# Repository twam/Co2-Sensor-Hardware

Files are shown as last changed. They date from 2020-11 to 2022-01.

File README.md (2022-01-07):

Co2-Sensor-Hardware
===

This repository is the hoftware part of the software project https://github.com/twam/Co2-Sensor-Software.

### Images

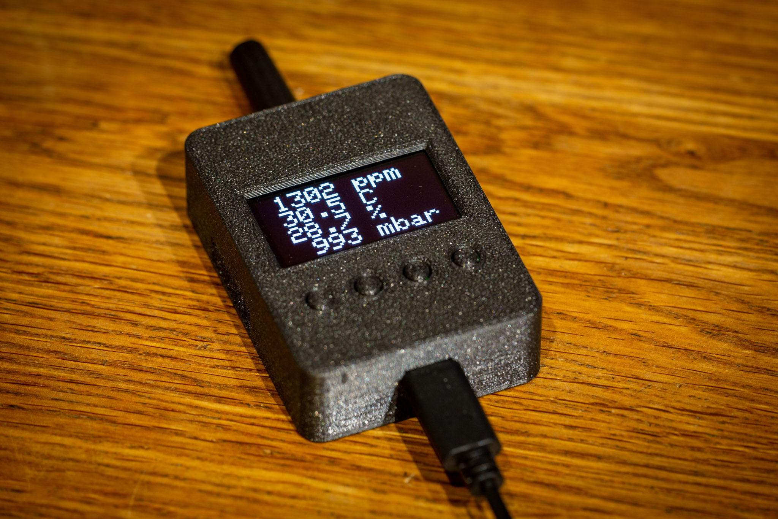
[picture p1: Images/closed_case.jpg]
Closed case

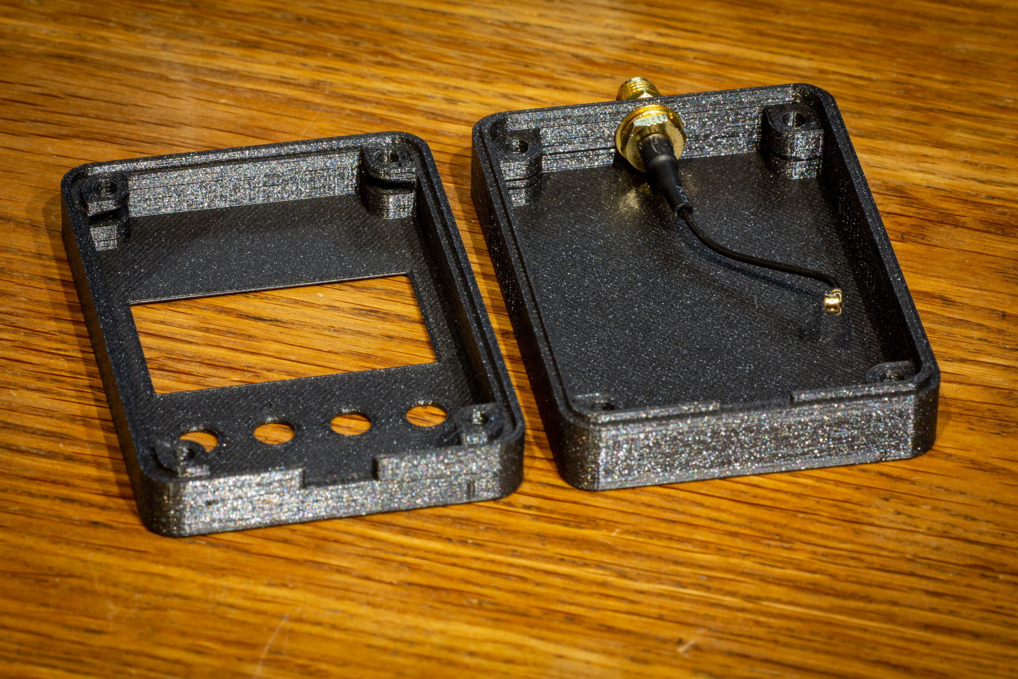
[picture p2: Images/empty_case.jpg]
Empty case

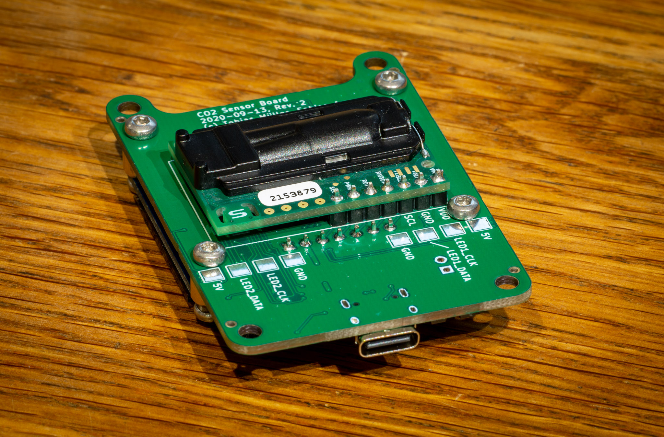
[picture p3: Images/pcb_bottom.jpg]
PCB bottom

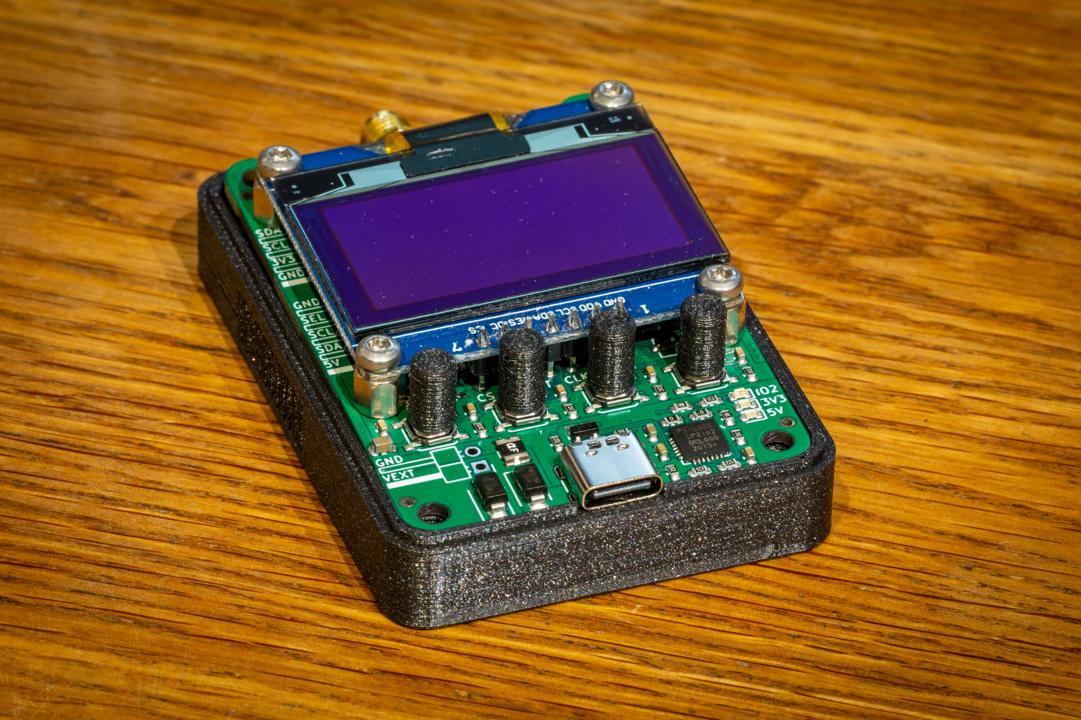
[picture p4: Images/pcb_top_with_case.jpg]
PCB top


### JLCPCB

PCBs can be ordered almost fully-assembled from [JLCPCB](https://jlcpcb.com/DDE). Required files are
[Co2-Sensor_bom_jlc.csv](Gerber/Co2-Sensor_bom_jlc.csv), [Co2-Sensor_cpl_jlc.csv](Gerber/Co2-Sensor_cpl_jlc.csv) and
[Co2-Sensor.zip](Co2-Sensor.zip). Components missing are
* Co2 Sensor (J2)
* USB connector (J5) – can be also populated in the mean time, but is not included in production files, yet.

## License

[][cc-by-sa]

This work is licensed under a [Creative Commons Attribution-NonCommercial-ShareAlike 4.0 International License][cc-by-sa].

[][cc-by-sa]

[cc-by-sa]: http://creativecommons.org/licenses/by-nc-sa/4.0/
[cc-by-sa-image]: https://licensebuttons.net/l/by-nc-sa/4.0/88x31.png
[cc-by-sa-shield]: https://img.shields.io/badge/License-CC%20BY--NC--SA%204.0-lightgrey.svg

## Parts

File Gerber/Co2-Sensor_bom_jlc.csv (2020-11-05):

Comment | Designator | Footprint | LCSC Part #
100n/50V | C2,C8,C9,C10,C11,C12,C13 | C_0603_1608Metric | C14663
1u/50V | C3 | C_0603_1608Metric | C15849
22u/25V | C4,C1,C14,C15 | C_0805_2012Metric | C45783
10u/10V | C5,C6 | C_0603_1608Metric | C19702
2u2/16V | C7 | C_0603_1608Metric | C23630
Green | D1,D4 | LED_0603_1608Metric | C72043
SS14 | D2,D6 | D_SMA | C2480
SP0503BAHT | D3 | SOT-143 | C7074
Yellow | D5 | LED_0603_1608Metric | C72038
SMD1210-050 | F1 | Fuse_1210_3225Metric | C70094
S8050 | Q1,Q2 | SOT-23 | C2146
2N7002 | Q3,Q4 | SOT-23 | C8545
0R | R5,R6,R33,R32,R30 | R_0603_1608Metric | C21189
10k | R7,R8,R3,R1,R17,R23,R27,R25 | R_0603_1608Metric | C25804
5k1 | R12,R11 | R_0603_1608Metric | C23186
24k | R13 | R_0603_1608Metric | C23352
47k | R14 | R_0603_1608Metric | C25819
4k7 | R15,R16 | R_0603_1608Metric | C23162
15k | R18 | R_0603_1608Metric | C22809
1k5 | R19 | R_0603_1608Metric | C22843
12k | R20 | R_0603_1608Metric | C22790
USER1 | SW1 | SW_SPST_XKB_TS-1187A-X-X-X | C318886
USER2 | SW2 | SW_SPST_XKB_TS-1187A-X-X-X | C318886
USER3 | SW3 | SW_SPST_XKB_TS-1187A-X-X-X | C318886
PROGRAM | SW4 | SW_SPST_XKB_TS-1187A-X-X-X | C318886
AMS1117-3.3 | U2 | SOT-223-3_TabPin2 | C6186
CP2102 | U3 | QFN-28-1EP_5x5mm_P0.5mm_EP3.35x3.35mm | C6568
74LVC1G02 | U5 | SOT-23-5 | C16360

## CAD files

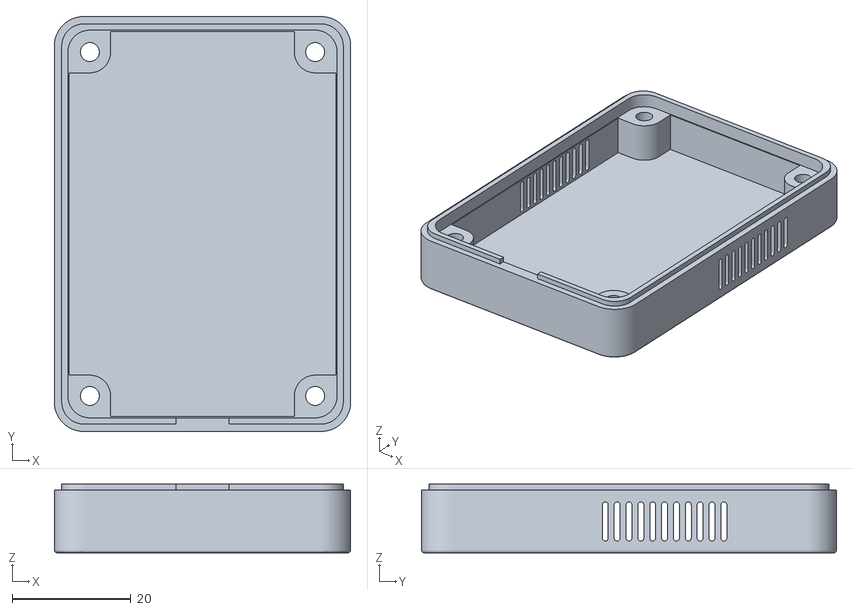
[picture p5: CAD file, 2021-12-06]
Case/Bottom_SideVentilation.stl
50.0 x 70.0 x 11.6

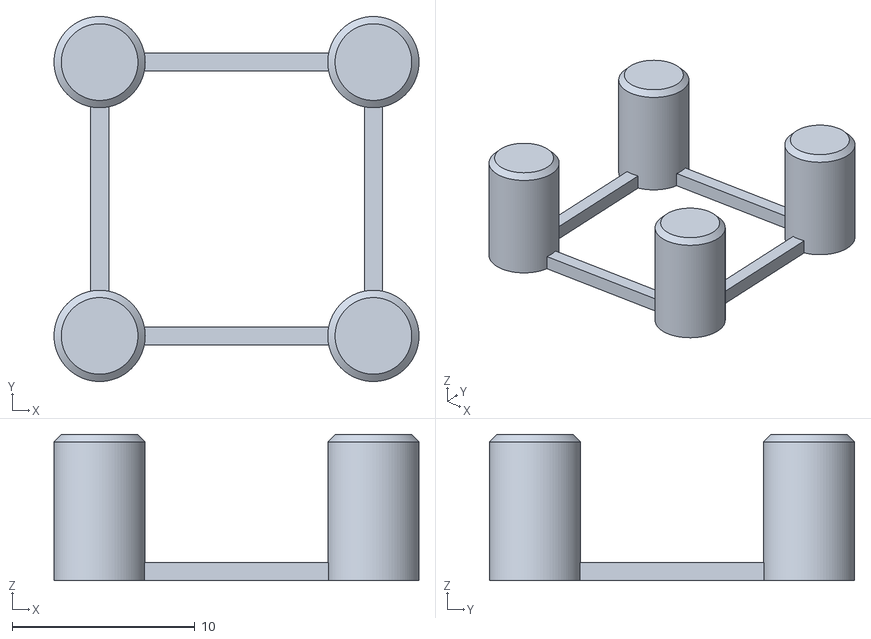
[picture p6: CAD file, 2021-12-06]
Case/Cap_4x.stl
20.0 x 20.0 x 8.00

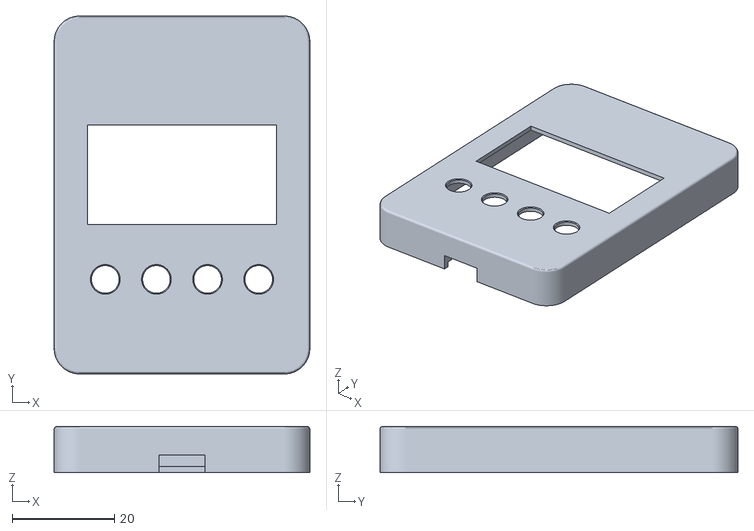
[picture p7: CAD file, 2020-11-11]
Case/Top.stl
50.0 x 70.0 x 9.00

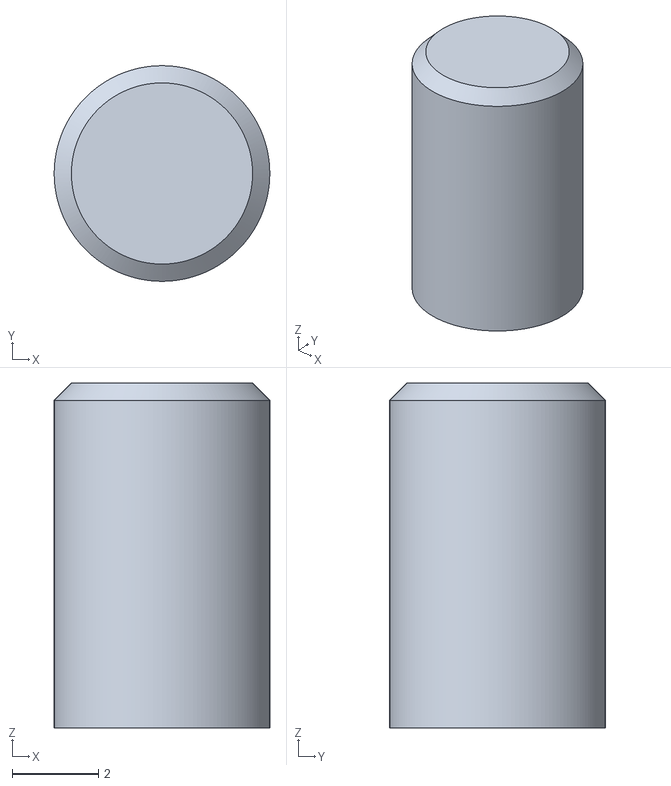
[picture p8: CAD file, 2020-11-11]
Case/Cap.stl
5.00 x 5.00 x 8.00

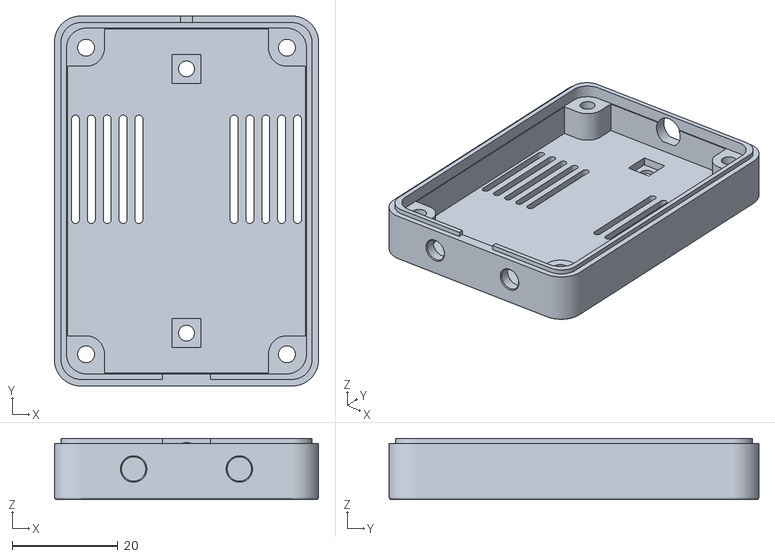
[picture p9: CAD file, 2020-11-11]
Case/Bottom_BottomVentilation_AntennaConnector_LEDCableOutlets.stl
50.0 x 70.0 x 11.6

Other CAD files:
Case/Bottom_SideVentTop.stl
Case/Bottom_SideVentTop_Ant.stl
Case/Bottom_SideVentilation_Ant.stl

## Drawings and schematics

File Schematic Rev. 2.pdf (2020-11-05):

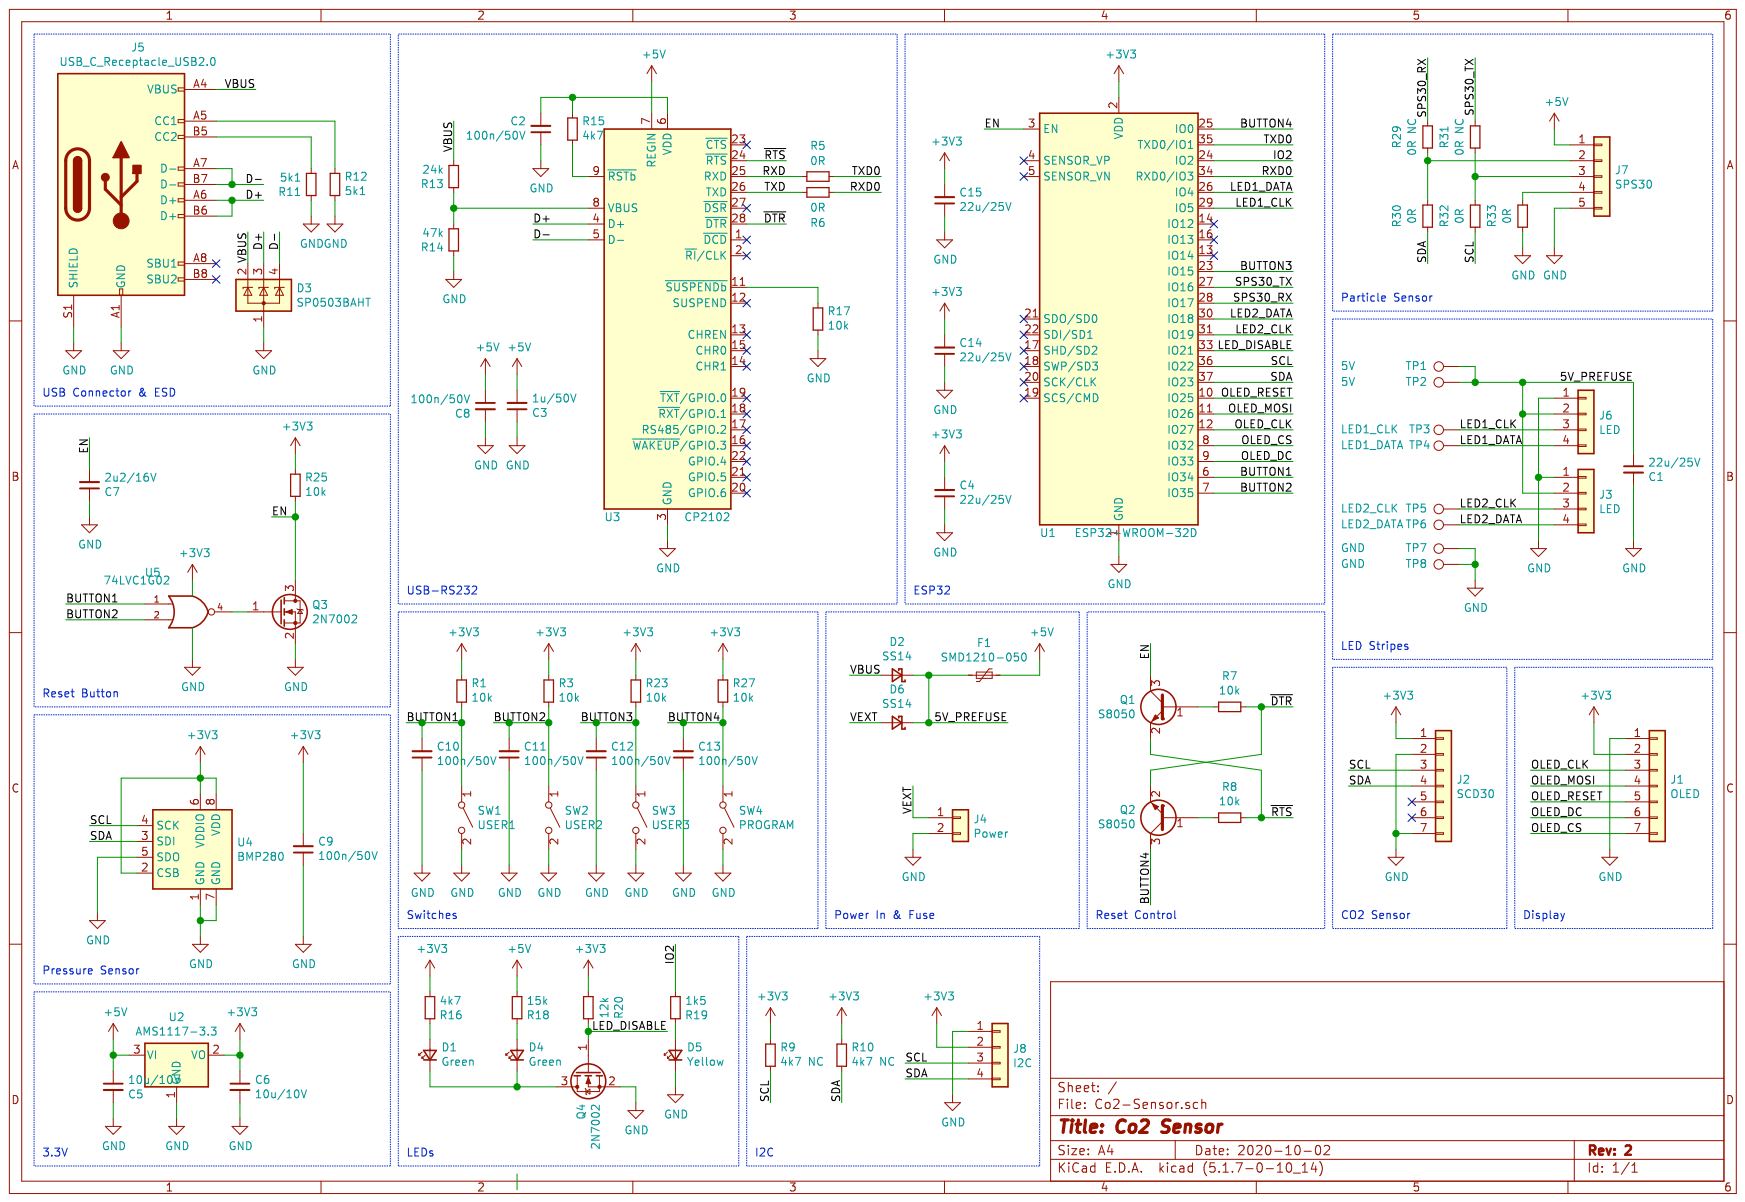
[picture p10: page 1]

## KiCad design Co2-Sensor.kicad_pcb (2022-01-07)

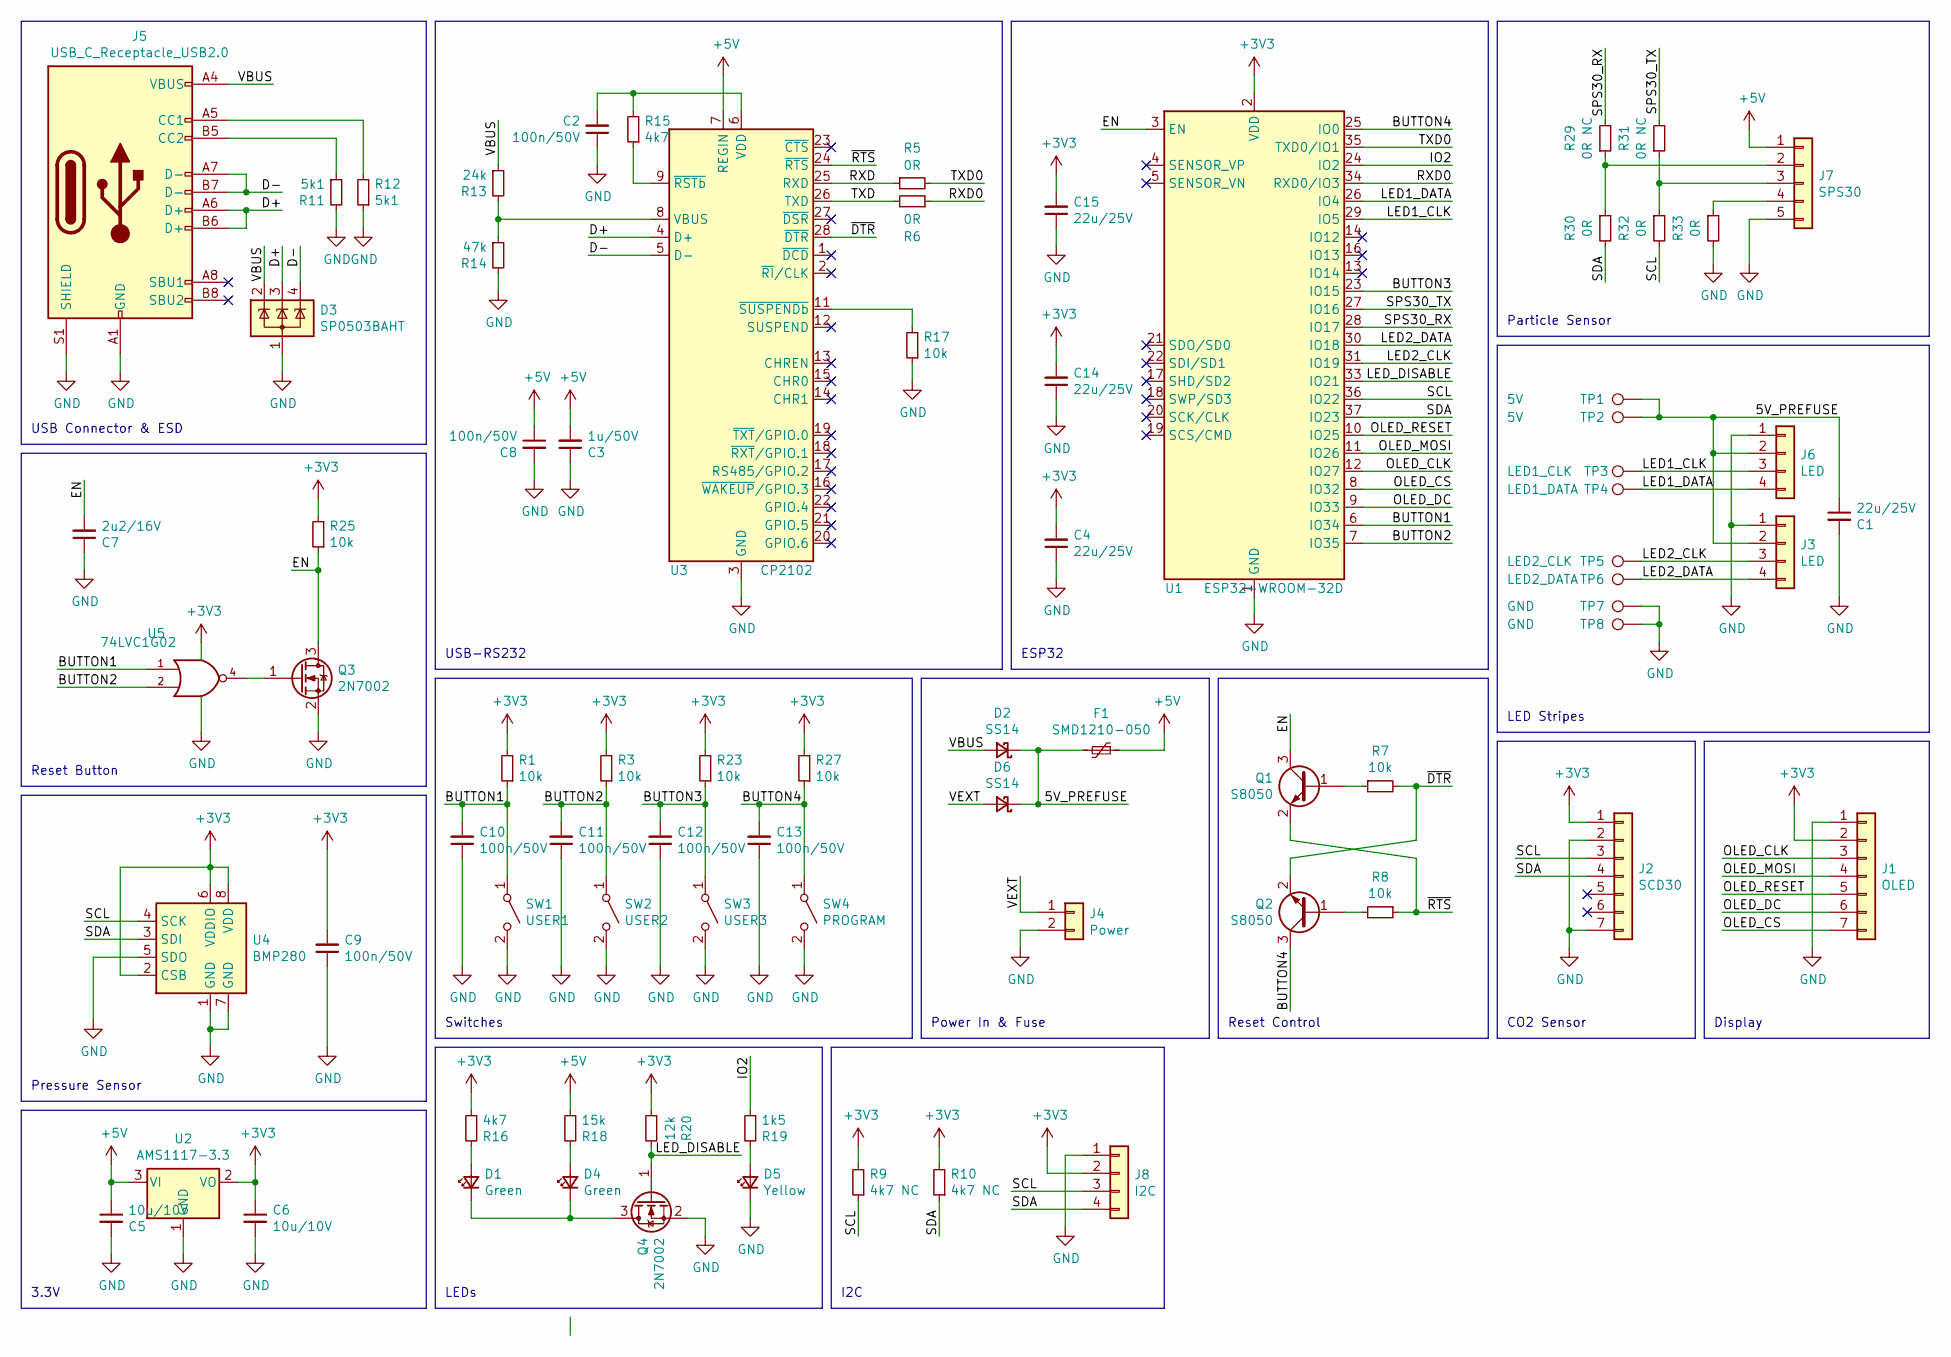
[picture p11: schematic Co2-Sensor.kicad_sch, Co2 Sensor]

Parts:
C1, C4, C14, C15: 22u/25V; C_0805_2012Metric; LCSC C45783
C2, C8, C9, C10, C11, C12, C13: 100n/50V; C_0603_1608Metric; LCSC C14663
C3: 1u/50V; C_0603_1608Metric; LCSC C15849
C5, C6: 10u/10V; C_0603_1608Metric; LCSC C19702
C7: 2u2/16V; C_0603_1608Metric; LCSC C23630
D1, D4: Green; LED_0603_1608Metric; LCSC C72043
D2, D6: SS14; D_SMA; LCSC C2480
D3: SP0503BAHT; SOT-143; LCSC C7074
D5: Yellow; LED_0603_1608Metric; LCSC C72038
F1: SMD1210-050; Fuse_1210_3225Metric; LCSC C70094
J1: OLED; TZT_154
J2: SCD30; Sensiron_SCD30
J3, J6: LED; PinHeader_1x04_P2.54mm_Horizontal
J4: Power; PinHeader_1x02_P2.54mm_Horizontal
J5: USB_C_Receptacle_USB2.0; USB_C_Receptacle_XKB_U262-16XN-4BVC11
J7: SPS30; PinHeader_1x05_P2.54mm_Horizontal
J8: I2C; PinHeader_1x04_P2.54mm_Horizontal
Q1, Q2: S8050; SOT-23; LCSC C2146
Q3, Q4: 2N7002; SOT-23; LCSC C8545
R1, R3, R7, R8, R17, R23, R25, R27: 10k; R_0603_1608Metric; LCSC C25804
R5, R6, R30, R32, R33: 0R; R_0603_1608Metric; LCSC C21189
R9, R10: 4k7 NC; R_0603_1608Metric
R11, R12: 5k1; R_0603_1608Metric; LCSC C23186
R13: 24k; R_0603_1608Metric; LCSC C23352
R14: 47k; R_0603_1608Metric; LCSC C25819
R15, R16: 4k7; R_0603_1608Metric; LCSC C23162
R18: 15k; R_0603_1608Metric; LCSC C22809
R19: 1k5; R_0603_1608Metric; LCSC C22843
R20: 12k; R_0603_1608Metric; LCSC C22790
R29, R31: 0R NC; R_0603_1608Metric
SW1: USER1; SW_SPST_XKB_TS-1187A-X-X-X; LCSC C318886
SW2: USER2; SW_SPST_XKB_TS-1187A-X-X-X; LCSC C318886
SW3: USER3; SW_SPST_XKB_TS-1187A-X-X-X; LCSC C318886
SW4: PROGRAM; SW_SPST_XKB_TS-1187A-X-X-X; LCSC C318886
TP1, TP2: 5V; TestPoint_Pad_2.5x2.5mm
TP3: LED1_CLK; TestPoint_Pad_2.5x2.5mm
TP4: LED1_DATA; TestPoint_Pad_2.5x2.5mm
TP5: LED2_CLK; TestPoint_Pad_2.5x2.5mm
TP6: LED2_DATA; TestPoint_Pad_2.5x2.5mm
TP7, TP8: GND; TestPoint_Pad_2.5x2.5mm
U1: ESP32-WROOM-32D; ESP32-WROOM-32
U2: AMS1117-3.3; SOT-223-3_TabPin2; LCSC C6186
U3: CP2102; QFN-28-1EP_5x5mm_P0.5mm_EP3.35x3.35mm; LCSC C6568
U4: BMP280; Bosch_LGA-8_2x2.5mm_P0.65mm_ClockwisePinNumbering; LCSC C83291
U5: 74LVC1G02; SOT-23-5; LCSC C16360

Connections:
+3V3: C4.2, C6.1, C9.2, C14.2, C15.2, J1.2, J2.1, J8.2, R1.2, R3.2, R9.2, R10.2, R16.1, R20.1, R23.2, R25.2, R27.2, U1.2 (VDD), U2.2 (VO), U4.2 (CSB), U4.6 (VDDIO), U4.8 (VDD), U5.5 (VCC)
+5V: C3.2, C5.1, C8.1, F1.1, J7.1, R18.1, U2.3 (VI), U3.7 (REGIN)
/5V_PREFUSE: C1.1, D2.1 (K), D6.1 (K), F1.2, J3.2, J6.2, TP1.1, TP2.1
/BUTTON1: C10.2, R1.1, SW1.1 (A), U1.6 (IO34), U5.1
/BUTTON2: C11.2, R3.1, SW2.1 (A), U1.7 (IO35), U5.2
/BUTTON3: C12.2, R23.1, SW3.1 (A), U1.23 (IO15)
/BUTTON4: C13.2, Q2.3 (C), R27.1, SW4.1 (A), U1.25 (IO0)
/D+: D3.3 (K), J5.A6 (D+), J5.B6 (D+), U3.4 (D+)
/D-: D3.4 (K), J5.A7 (D-), J5.B7 (D-), U3.5 (D-)
/EN: C7.2, Q1.3 (C), Q3.3 (D), R25.1, U1.3 (EN)
/IO2: R19.1, U1.24 (IO2)
/LED1_CLK: J6.3, TP3.1, U1.29 (IO5)
/LED1_DATA: J6.4, TP4.1, U1.26 (IO4)
/LED2_CLK: J3.3, TP5.1, U1.31 (IO19)
/LED2_DATA: J3.4, TP6.1, U1.30 (IO18)
/LED_DISABLE: Q4.1 (G), R20.2, U1.33 (IO21)
/OLED_CLK: J1.3, U1.12 (IO27)
/OLED_CS: J1.7, U1.8 (IO32)
/OLED_DC: J1.6, U1.9 (IO33)
/OLED_MOSI: J1.4, U1.11 (IO26)
/OLED_RESET: J1.5, U1.10 (IO25)
/RXD: R5.1, U3.25 (RXD)
/RXD0: R6.1, U1.34 (RXD0/IO3)
/SCL: J2.3, J8.3, R9.1, R32.2, U1.36 (IO22), U4.4 (SCK)
/SDA: J2.4, J8.4, R10.1, R30.2, U1.37 (IO23), U4.3 (SDI)
/SPS30_RX: R29.2, U1.28 (IO17)
/SPS30_TX: R31.2, U1.27 (IO16)
/TXD: R6.2, U3.26 (TXD)
/TXD0: R5.2, U1.35 (TXD0/IO1)
/VBUS: D2.2 (A), D3.2 (K), J5.A4 (VBUS), J5.A9 (VBUS), J5.B4 (VBUS), J5.B9 (VBUS), R13.1
/VEXT: D6.2 (A), J4.1
/~DTR: Q2.2 (E), R7.2, U3.28 (~DTR)
/~RTS: Q1.2 (E), R8.1, U3.24 (~RTS)
GND: C1.2, C2.1, C3.1, C4.1, C5.2, C6.2, C7.1, C8.2, C9.1, C10.1, C11.1, C12.1, C13.1, C14.1, C15.1, D3.1 (A), D5.1 (K), J1.1, J2.2, J2.7, J3.1, J4.2, J5.A1 (GND), J5.A12 (GND), J5.B1 (GND), J5.B12 (GND), J5.S1 (SHIELD), J6.1, J7.5, J8.1, Q3.2 (S), Q4.2 (S), R11.2, R12.1, R14.2, R17.1, R33.2, SW1.2 (B), SW2.2 (B), SW3.2 (B), SW4.2 (B), TP7.1, TP8.1, U1.1 (GND), U1.15 (GND), U1.38 (GND), U1.39 (GND), U2.1 (GND), U3.3 (GND), U3.29 (GND), U4.1 (GND), U4.5 (SDO), U4.7 (GND), U5.3 (GND)
unnamed: C2.2, R15.2, U3.6 (VDD)
unnamed: D1.1 (K), D4.1 (K), Q4.3 (D)
unnamed: D1.2 (A), R16.2
unnamed: D4.2 (A), R18.2
unnamed: D5.2 (A), R19.2
unnamed: J5.A5 (CC1), R12.2
unnamed: J5.B5 (CC2), R11.1
unnamed: J7.2, R29.1, R30.1
unnamed: J7.3, R31.1, R32.1
unnamed: J7.4, R33.1
unnamed: Q1.1 (B), R7.1
unnamed: Q2.1 (B), R8.2
unnamed: Q3.1 (G), U5.4
unnamed: R13.2, R14.1, U3.8 (VBUS)
unnamed: R15.1, U3.9 (~RSTb)
unnamed: R17.2, U3.11 (~SUSPENDb)

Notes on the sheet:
LED Stripes
I2C
Reset Control
CO2 Sensor
Switches
ESP32
Reset Button
Power In & Fuse
USB Connector & ESD
Particle Sensor
3.3V
USB-RS232
LEDs
Display
Pressure Sensor

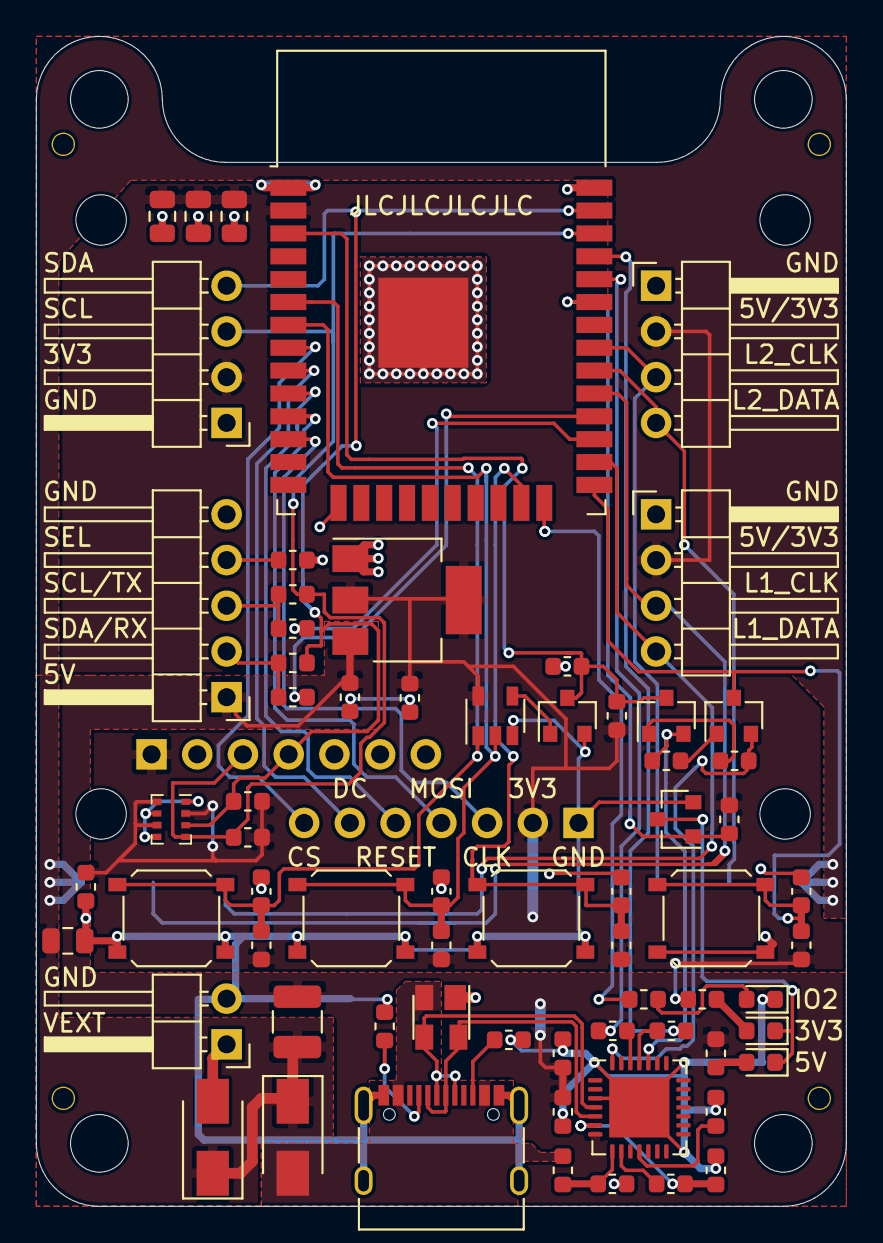
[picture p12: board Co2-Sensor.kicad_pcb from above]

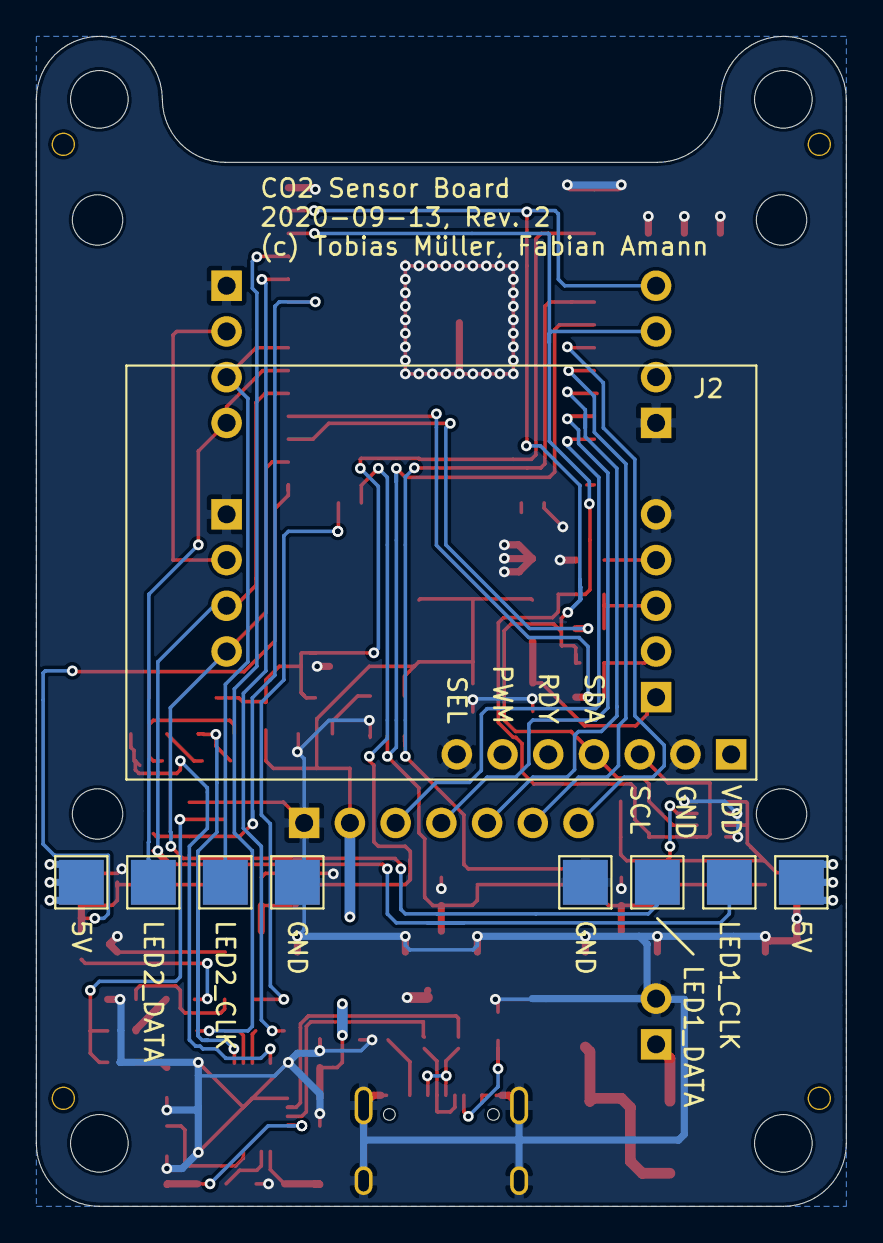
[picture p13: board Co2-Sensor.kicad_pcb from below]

Board: 2 copper layers, 45.0 x 65.0 mm, 77 parts (9 on the bottom side), 50 nets.

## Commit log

2020-10-02 Add changes for Rev. 2
    [Co2-Sensor.kicad_pcb, Co2-Sensor.sch]
2020-10-03 Minor improvements
    [Co2-Sensor.kicad_pcb, Co2-Sensor.sch]
2020-10-04 Add more capacitance to ESP
    [Co2-Sensor.kicad_pcb, Co2-Sensor.sch]
2020-11-05 Revision 2
    [Co2-Sensor-B_Cu.gbr, Co2-Sensor-B_Mask.gbr, Co2-Sensor-B_Paste.gbr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]
2020-11-05 Add schematic as PDF
2020-11-11 Add case
    [Bottom_BottomVentilation_AntennaConnector_LEDCableOutlets.stl, Bottom_SideVentilation_AntennaConnector.stl, Cap.stl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]
2021-12-06 Add more case variants
    [Bottom_SideVentTop.stl, Bottom_SideVentTop_Ant.stl, Bottom_SideVentilation.stl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]
2022-01-07 Move JLCPCB files to Gerber
    [Co2-Sensor_bom_jlc.csv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]
2022-01-07 Update to KiCad 6
    [Co2-Sensor.kicad_pcb, Co2-Sensor.kicad_sch, Co2-Sensor.sch]
